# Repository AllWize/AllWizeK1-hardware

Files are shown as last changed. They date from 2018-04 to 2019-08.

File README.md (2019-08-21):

# AllWize K1

The Allwize K1 shield is an Arduino-compatible shield based on the RadioCrafts RC1701HP module. 

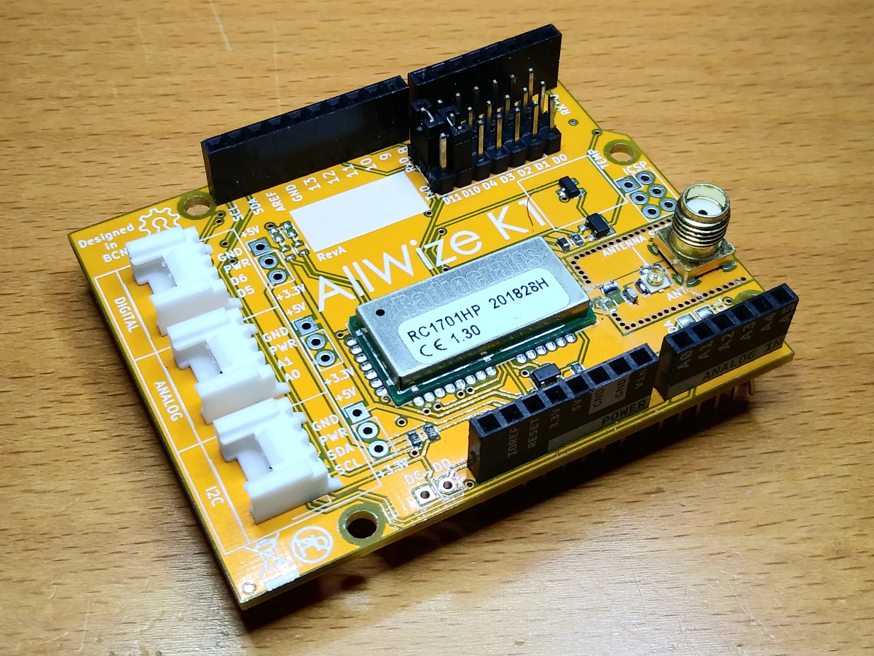
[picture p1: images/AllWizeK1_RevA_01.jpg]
AllWize K1 RevA


Resources:

* [AllWize K1 Wiki Page](http://wiki.allwize.io/index.php?title=Allwize_K1)
* [AllWize Library](https://github.com/AllWize/allwize) that supports the RC1701HP radio module.

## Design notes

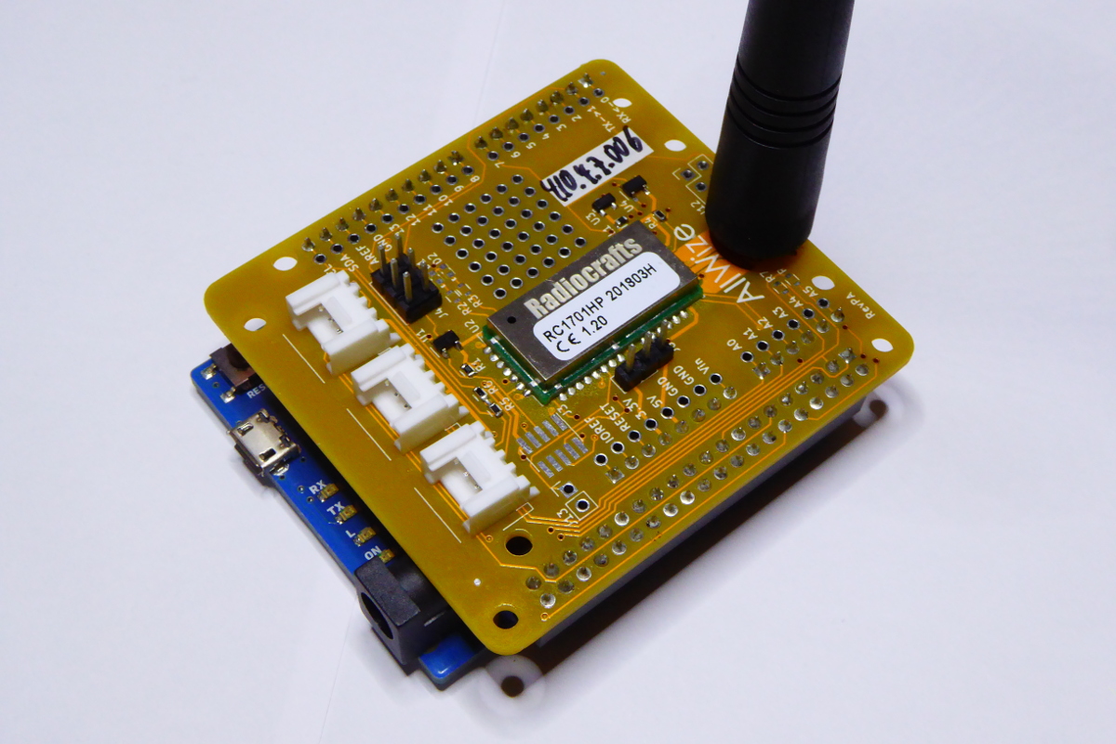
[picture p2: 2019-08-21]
images/AllWizeK1_RevPA_01.jpg

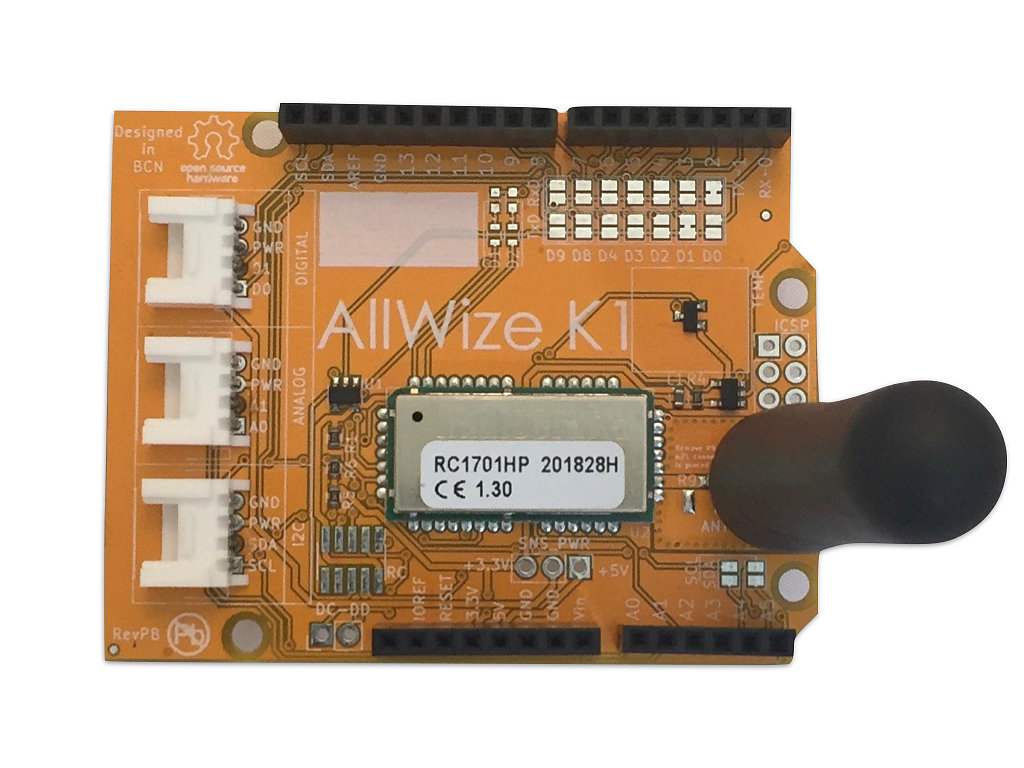
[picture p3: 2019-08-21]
images/AllWizeK1_RevPB_01.jpg

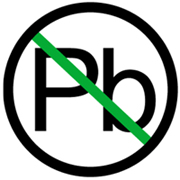
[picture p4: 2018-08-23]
RevA/Pb-free.jpg

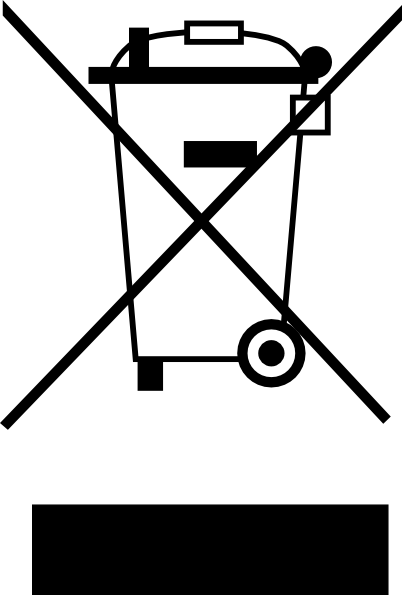
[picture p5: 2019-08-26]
RevA/WEEE.png

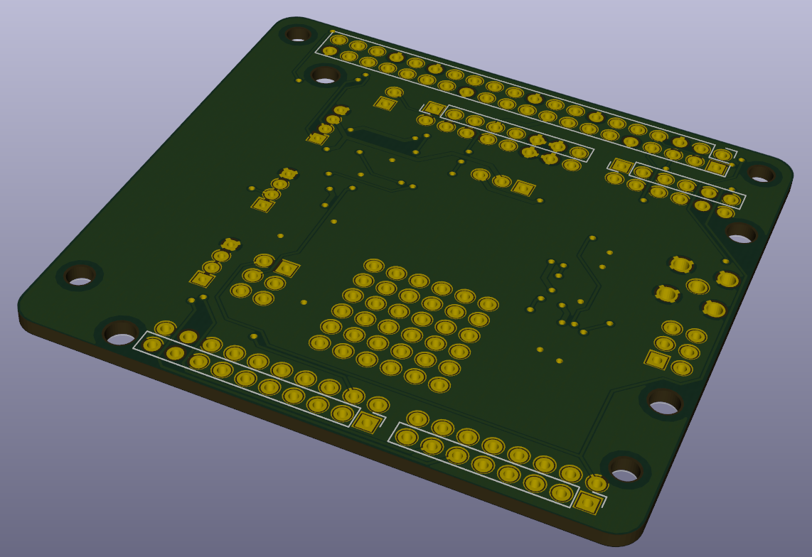
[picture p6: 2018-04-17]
RevPA/pcb/PCB-view-2-BOTTOM.png

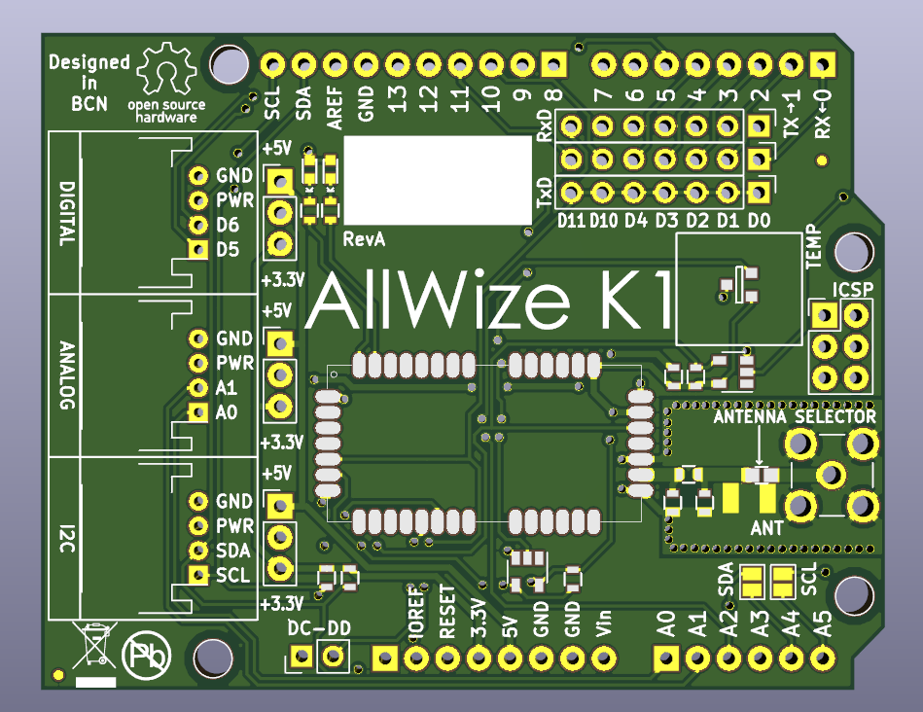
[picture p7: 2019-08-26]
RevA/gerbers/fanfkeofkpelmadl.png

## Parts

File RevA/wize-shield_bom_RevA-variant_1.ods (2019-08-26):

Part | References | Value | Quantity Per PCB | Function | PN | Populated
LED-DIODE | D1 D2 | LED-DIODE | 2 | Green LED | KPT-1608LVZGCK | No
LOGO | G2 | LABEL | 1 | Label Zone | NA | No
LOGO | G1 | LOGO | 1 | Logo Mark | NA | No
LOGO | G3 | PROTOTYPE-AREA | 1 | 6x6 Prototype Area | NA | No
Conn_01x02 | J13 | Conn_01x02 | 1 | 1x2 Connector | NA | No
Conn_01x03 | J6 J19 J20 | Conn_01x03 | 3 | 1x3 Connector | PEC03SAAN | Yes | https://www.digikey.es/products/es?keywords=PEC03SAAN
Conn_01x04 | J7 J8 J9 | Conn_01x04 | 3 | 1x4 Connector | 110990037 | Yes | https://www.digikey.es/products/es?keywords=110990037
Conn_01x06 | J2 | Conn_01x06 | 1 | 1x6 Connector | PEC06SAAN | Yes | https://www.digikey.es/products/es?keywords=PEC06SAAN
Conn_01x06 | J24 | Conn_01x06 | 1 | 1x6 Connector | NA | No
Conn_01x07 | J14 J17 J18 | Conn_01x07 | 3 | 1x7 Connector | PEC07SAAN | Yes | https://www.digikey.es/products/es?keywords=PEC07SAAN
Conn_01x08 | J1 J11 | Conn_01x08 | 2 | 1x8 Connector | PEC08SAAN | Yes | https://www.digikey.es/products/es?keywords=PEC08SAAN
Conn_01x08 | J23 J26 | Conn_01x08 | 2 | 1x8 Connector | NA | No
Conn_01x10 | J10 | Conn_01x10 | 1 | 1x10 Connector | PEC10SAAN | Yes | https://www.digikey.es/products/es?keywords=PEC10SAAN
Conn_01x10 | J25 | Conn_01x10 | 1 | 1x10 Connector | NA | No
Conn_02x03_Odd_Even | J12 | Conn_02x03_Odd_Even | 1 | 2x3 Connector | NA | No
Conn_02x03_Odd_Even | J4 | Conn_02x03_Odd_Even | 1 | 2x3 Connector | PEC03DAAN | Yes | https://www.digikey.es/products/es?keywords=PEC03DAAN
Conn_02x05_Odd_Even | J3 | Conn_02x05_Odd_Even | 1 | 2x5 Connector | NA | No
Conn_02x20_Odd_Even | J14 | Conn_02x20_Odd_Even | 1 | 2x20 Connector | PPTC202LFBN-RC | Yes | https://www.digikey.es/products/es?keywords=PPTC202LFBN-RC
Conn_Coaxial | J5 | Conn_Coaxial | 1 | SMA Antenna Connector | PCB.SMAFST.J.A.HT | Yes | https://www.digikey.es/product-detail/es/taoglas-limited/PCB.SMAFST.J.A.HT/931-1173-ND/3522339
NPTH-HOLE | J15 J16 J17 J18 J19 J20 J21 J22 | NPTH-HOLE | 8 | NPTH Hole | NA | No
Ferrite_Bead | L1 | Ferrite_Bead | 1 | Ferrite Bead | BLM18SG331TN1 | Yes | https://www.digikey.es/product-detail/es/murata-electronics-north-america/BLM18SG331TN1D/490-3997-1-ND/1016257
--------------------- | R7 R8 R10 | PI Filter | --------------------- | --------------------- | TBD
R | R2 R3 | 1k | 2 | Series Resistor | RC0603FR-071KL | No
R | R4 R5 R6 | 5k6 | 3 | Pull-up resistor | ERJ-3EKF5601V | Yes | https://www.digikey.es/product-detail/es/panasonic-electronic-components/ERJ-3EKF5601V/P5.60KHCT-ND/1746792
R | R1 | 8k2 | 1 | Pull-up resistor | CRCW06038K20FKEA | Yes | https://www.digikey.es/product-detail/es/vishay-dale/CRCW06038K20FKEA/541-8.20KHCT-ND/1179913
MCP9701 | U3 | MCP9701 | 1 | Temperature Sensors | MCP9701T-E/TT | Yes | https://www.digikey.es/product-detail/es/microchip-technology/MCP9701T-E-TT/MCP9701T-E-TTCT-ND/1987446
RC1701xx-MBUS | U2 | RC1701xx-MBUS | 1 | M-Bus High power RF Transceiver Module | RC1701HP-MBUS4 | Yes | https://www.digikey.es/product-detail/es/radiocrafts-as/RC1701HP-MBUS4/1783-1048-1-ND/7100650
SN74LV1T34 | U1 U4 | SN74LV1T34 | 2 | Logic Level Shifter | SN74LV1T34DBVR | Yes | https://www.digikey.es/product-detail/es/texas-instruments/SN74LV1T34DBVR/296-37176-1-ND/4555593
uFL | J4 | U.FL-R-SMT(10) | 1 | u.FL Antenna Connector | U.FL-R-SMT(10) | No | https://www.digikey.es/products/es?keywords=%20H9161CT-ND
R | R9 | 0R | 1 | Series Resistor | CRCW06030000Z0EAC | Yes
Jumper |  |  | 1 | Jumper | 969102-0000-DA | Yes | https://www.digikey.es/products/es?keywords=969102-0000-DA

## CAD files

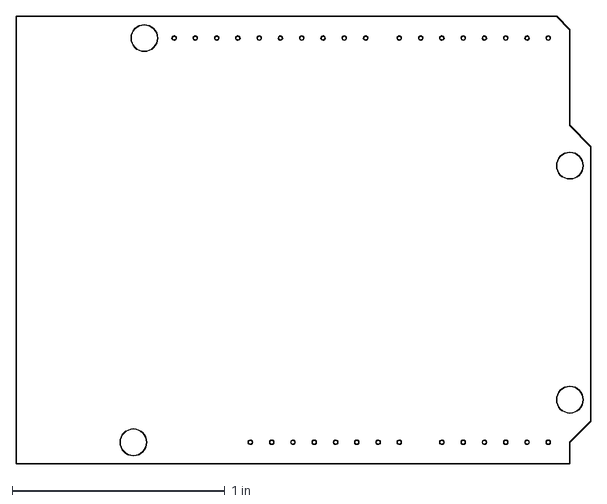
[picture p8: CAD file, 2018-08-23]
RevA/Arduino UNO R3 shield - full.dxf
2.70 x 2.10 in

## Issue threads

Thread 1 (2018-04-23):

[AllWize] Via annular ring too short (General)

amejias, 2018-04-23:
Some pads needs more annular ring space. This can provoke bad fixation on PCB.

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

xoseperez, 2018-09-19:
Fixed with RevPB

Closed 2018-09-19.

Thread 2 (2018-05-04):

[Allwize] Missing assembly plan

arcediano90, 2018-05-04:
Missing designators J1, J2, J10, J11, J14

xoseperez, 2018-09-19:
Is there an assembly plan already?

AllWize, 2018-11-16:
Already on the repository ... documents .Fab

Closed 2018-11-16.

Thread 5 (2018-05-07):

[Allwize] Missing info in the silkscreen

AllWize, 2018-05-07:
I'm missing proper information in the silkscreen for these designators

- J3 (RC programming header) - RC
- J4 (serial selector) - UART
- J6 (sensor reference) - SNS_PWR
- J7 (I2C grove connector) - I2C
- J8 (Analog grove connector: A0, A1) - ANA
- J9 (Digital grove connector: D5, D6) - DIO
- J12 (ICSP) - ICSP
- J13 (module flashing, not sure this is needed since it's still a testing feature)

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

xoseperez, 2018-09-19:
Fixed with RevPB

Closed 2018-09-19.

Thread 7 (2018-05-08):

[Allwize] Indicate jumper configuration

arcediano90, 2018-05-08:
Indicate in silkscreen the jumper configuration

xoseperez, 2018-09-19:
Fixed with Rev.PB for the only jumper left, the sensor power jumper.

Closed 2018-09-19.

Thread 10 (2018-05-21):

Mark the temperature sensor as "Temperature sensor" not "Ux"

mfabregas, 2018-05-21:
Will give a better understanding and user experience if the user knows which IC is the temperature sensor, in order to play with it. Since he/she likely will touch it, will be good to have it in an accessible location, far from other ICs, jumpers and components

xoseperez, 2018-09-19:
Done with Rev.PB

Closed 2018-09-19.

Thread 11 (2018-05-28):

Grove connector pins are swapped

xoseperez, 2018-05-28:
The pins in the grove connectors are swapped, we should swap pin 1 with 4 and 2 with 3

xoseperez, 2018-09-19:
Fixed with Rev.PB

Closed 2018-09-19.

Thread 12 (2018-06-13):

Use stackable headers & remove proto zone

AllWize, 2018-06-13:
Even if the K1 is forced to be a top-shield, it is interesting to mount stackable headers (with female holes on top) so there is no need to solder the extra rows of headers to have easy access to other GPIOs.

xoseperez, 2018-09-19:
Done with Rev.PB

xoseperez, 2018-09-19:
BTW, see https://store.arduino.cc/headers-strip-14-ways-arduino-mkr1000-printed

Closed 2018-09-19.

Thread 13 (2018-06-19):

Replace the arrows in the silkscreen

AllWize, 2018-06-19:
At the moment the arrow in the RX/TX ports is done using two characters (-> or <-). In order to save some room it will be interesting to use a single character symbol.

xoseperez, 2018-09-19:
Fixed with Rev.PB

Closed 2018-09-19.

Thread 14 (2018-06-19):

Remove Raspberry Pi Connector

AllWize, 2018-06-19:
We will think about creating a G1 version in the future for Raspberry Pi, but at the moment we don't see any benefit in having the Raspberry Pi header in the K1.

xoseperez, 2018-09-19:
Done with Rev.PB

Closed 2018-09-19.

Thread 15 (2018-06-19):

Add uFL footprint

AllWize, 2018-06-19:
The main benefit is that we will not be limited to be a top shield. Right now the issue is the lack of (good) 90 degrees antenna.

It's OK if it's to factory-ready that would require a solder-jumper change.
Or even better, place the uFL footprint in the path, not mounted, and a resistor bridge that should be removed before placing the uFL, the same pad of the resistor would double and uFL live.

xoseperez, 2018-09-19:
Done with Rev.PB

Closed 2018-09-19.

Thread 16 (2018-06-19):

Use hardware serial by default

AllWize, 2018-06-19:
We think it will ease the use of the board to remove the jumper selector and set it to hardware serial by default with solder pads to allow the user to cut and solder a different option. Very much like this board:

https://github.com/ttn-liv/LoRaWANshield

Options: 0 (default for RX),1 (default for TX), 2, 3, 4, 8 and 9.

xoseperez, 2018-09-19:
Done with Rev.PB

Closed 2018-09-19.

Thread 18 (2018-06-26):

General labelling

xoseperez, 2018-06-26:
Several changes:

* Board must be named "Allwize K1"
* Make the while label zone bigger
* Increase font size, make it the same size as an Arduino
* Add as much GND as possible on both sides
* OSH logo (on top) (https://www.oshwa.org/open-source-hardware-logo/)
* "Made in BCN"
* Compliance logos (CE, ~~ROHS~~)

xoseperez, 2018-09-19:
Done with Rev.PB

Closed 2018-09-19.

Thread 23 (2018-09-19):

Add BOM to the repository

xoseperez, 2018-09-19:
A BOM file (no special format required) must be added to the repo si be fully open source hardware.

xoseperez, 2018-09-19:
See https://store.arduino.cc/headers-strip-14-ways-arduino-mkr1000-printed for the headers reference.

AllWize, 2018-10-01:
@arcediano90 to add it

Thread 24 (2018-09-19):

Digital grove connector label is wrong

xoseperez, 2018-09-19:
It should state that the connected pins are D5 and D6, and not D0 and D1 as it says.

Closed 2018-12-19.

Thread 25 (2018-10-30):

Change Pin Header position

arcediano90, 2018-10-30:
For the future Revision, change the position pin header connector:

SNS_PWR connector (pin header) next to grove connectors

AllWize, 2018-11-16:
See issue #27

Closed 2018-11-16.

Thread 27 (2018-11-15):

Sensor's power pins next to connectors

AllWize, 2018-11-15:
It does not make sense to pot the power pins SNS_PWR so far from the connectors; why not putting it next to the Grove connector?
Moreover, maybe make sense to put one of them for each sensor

AllWize, 2018-11-16:
The label indicating the type of connector is moved to the board edge, where the connector is plugged (right now this is an empty space)

Closed 2018-12-18.

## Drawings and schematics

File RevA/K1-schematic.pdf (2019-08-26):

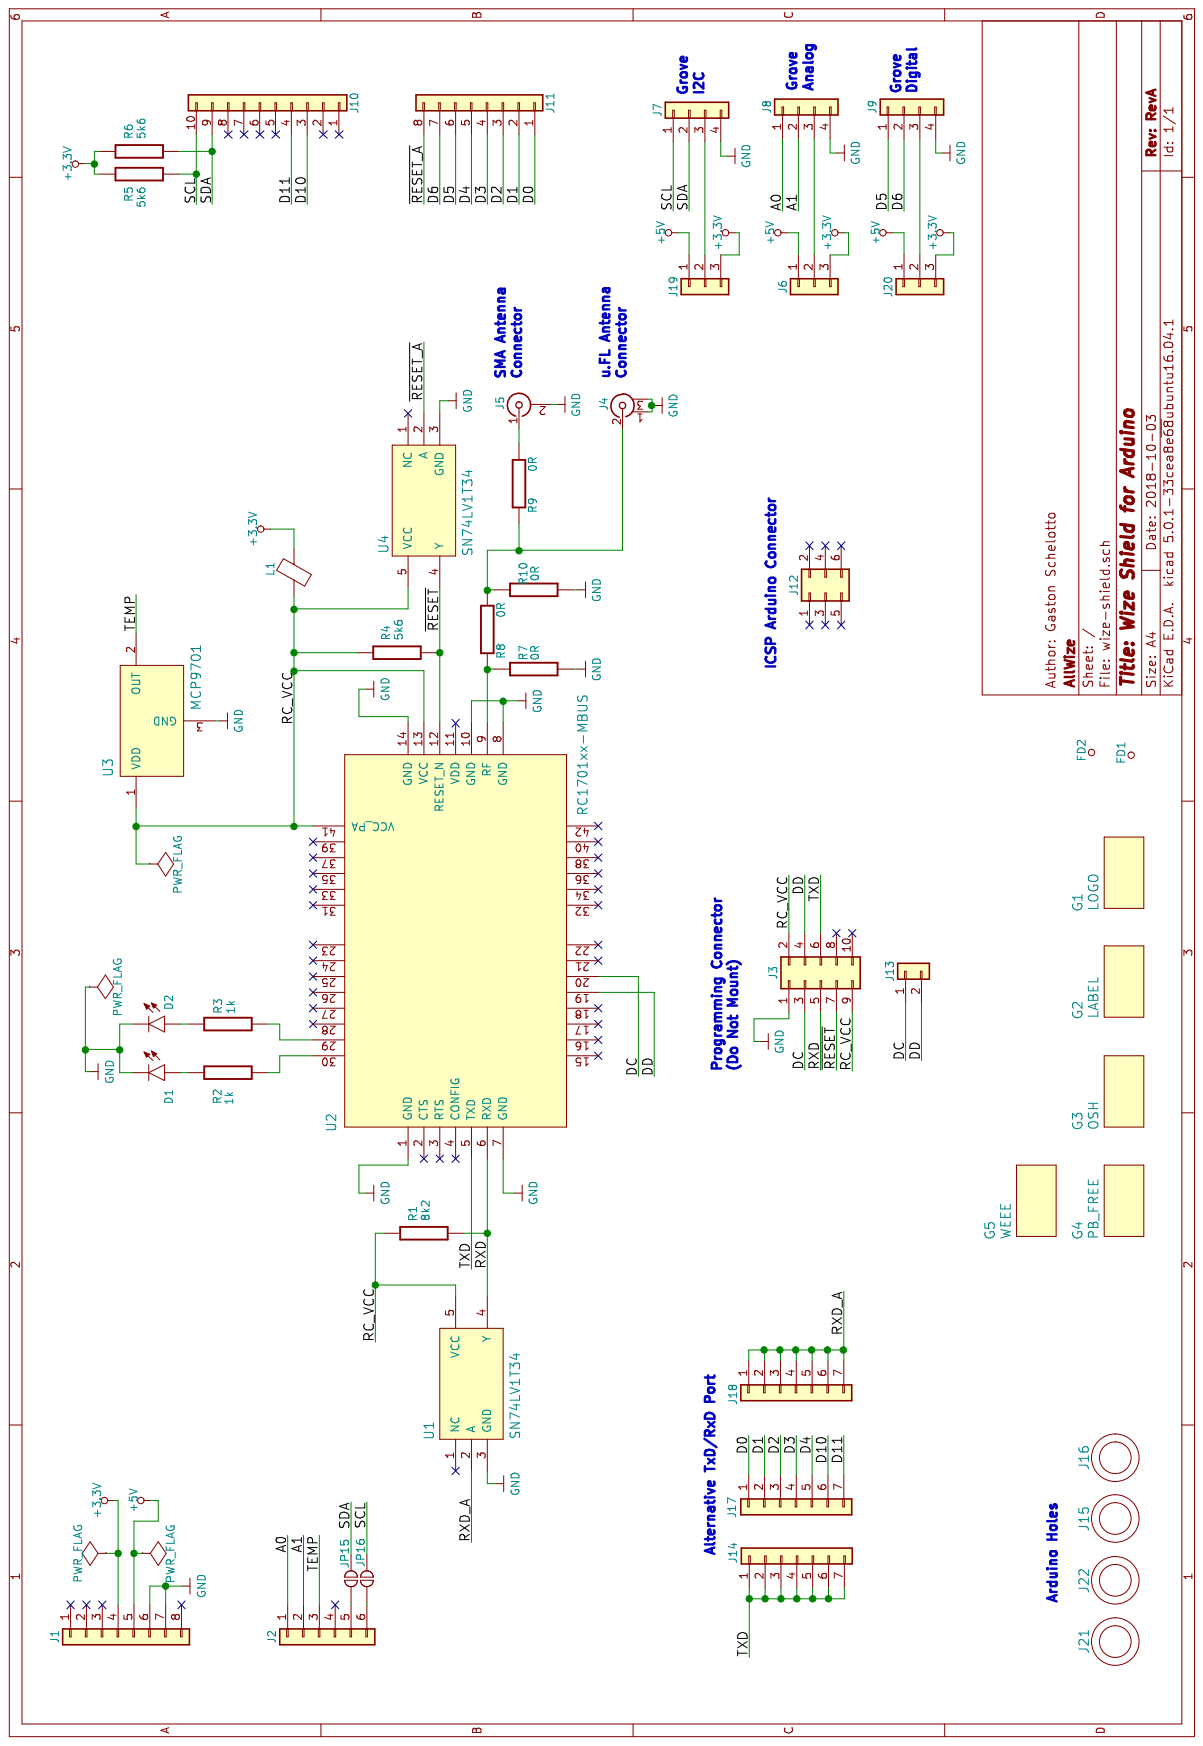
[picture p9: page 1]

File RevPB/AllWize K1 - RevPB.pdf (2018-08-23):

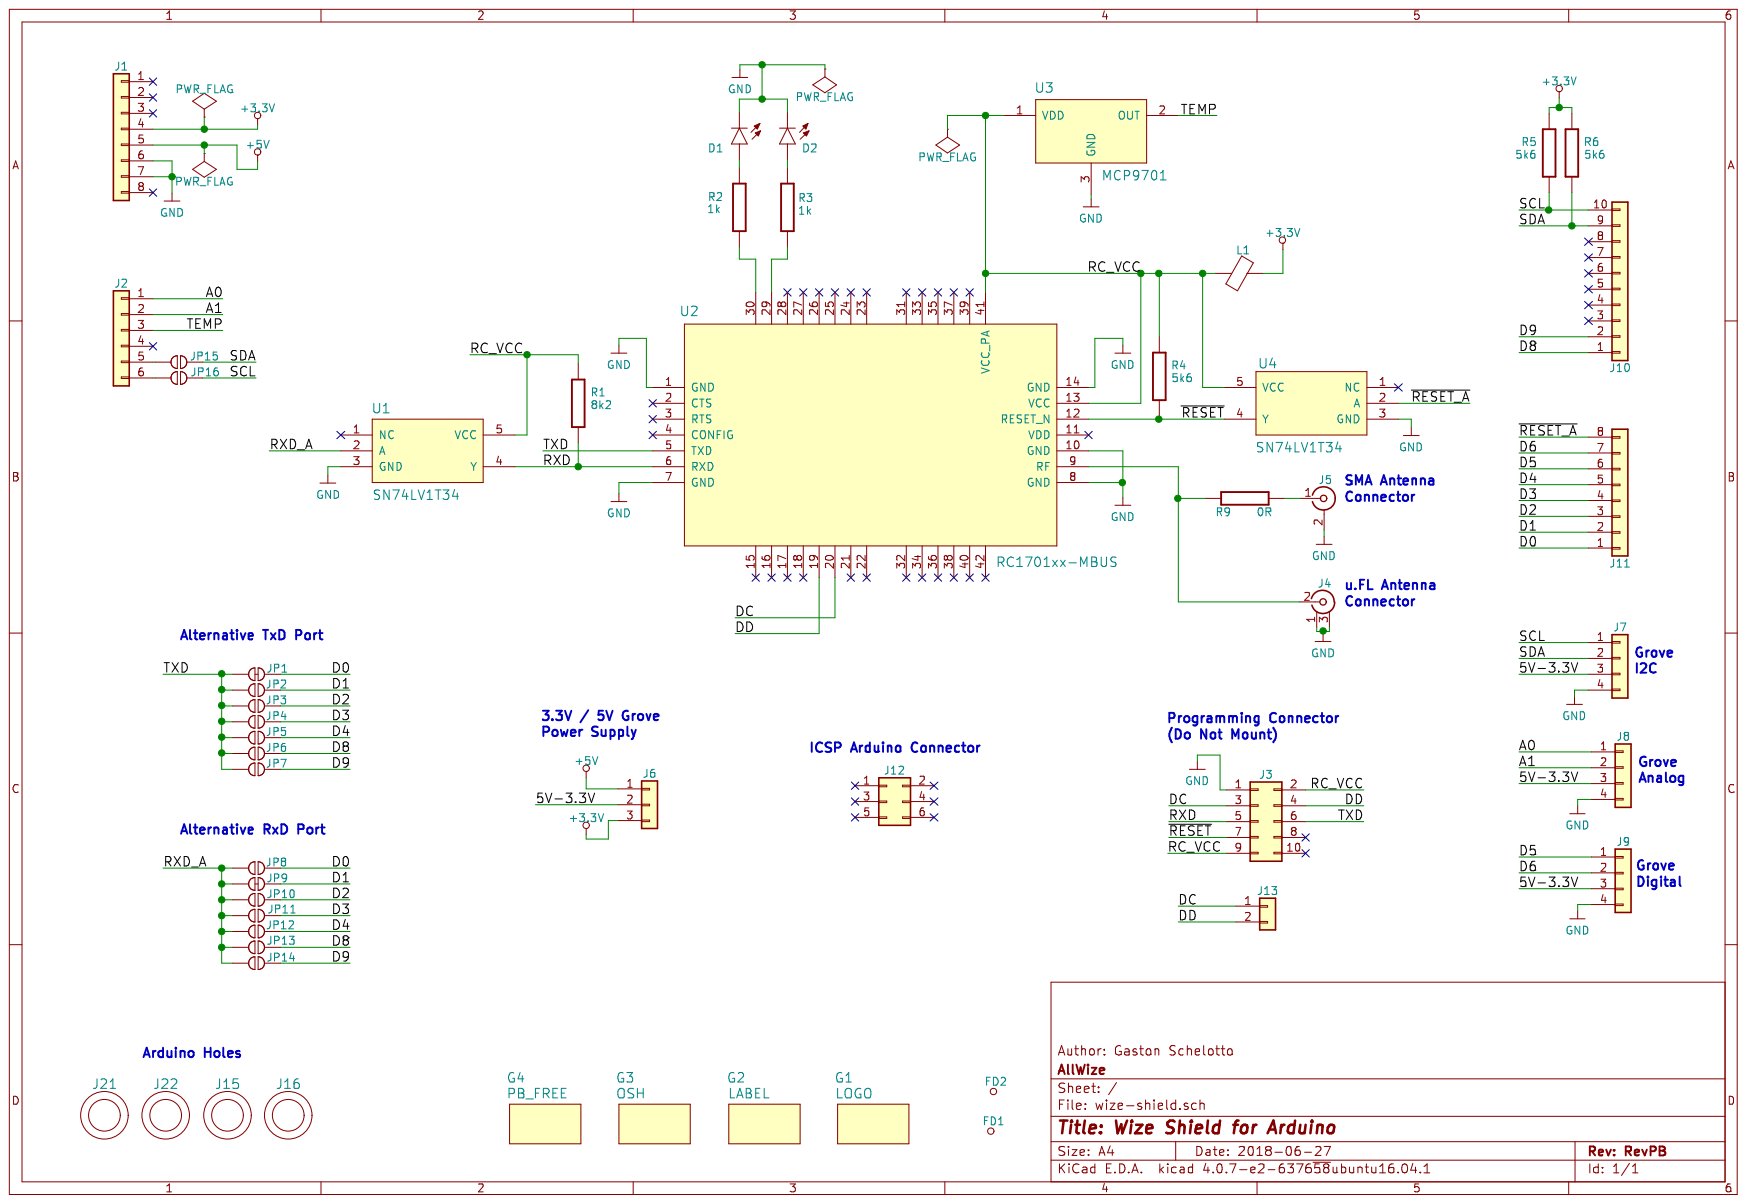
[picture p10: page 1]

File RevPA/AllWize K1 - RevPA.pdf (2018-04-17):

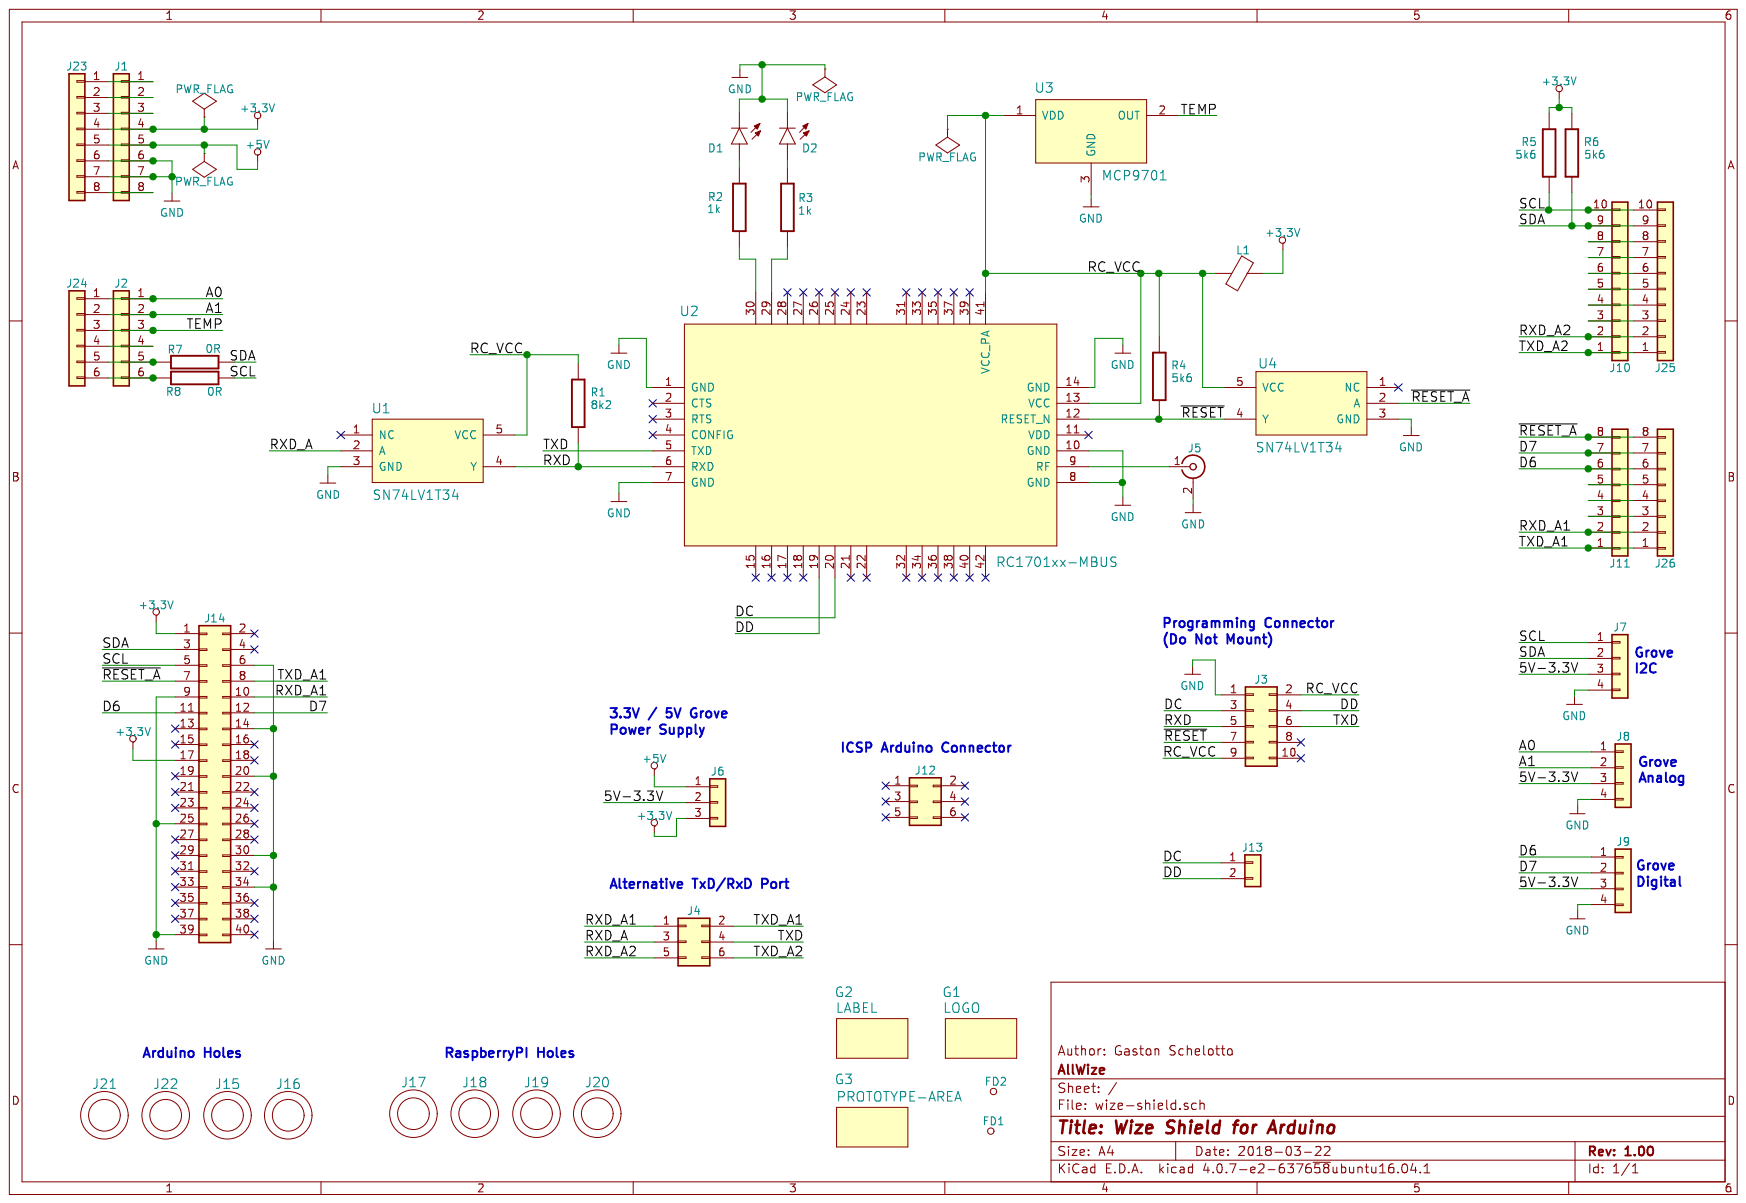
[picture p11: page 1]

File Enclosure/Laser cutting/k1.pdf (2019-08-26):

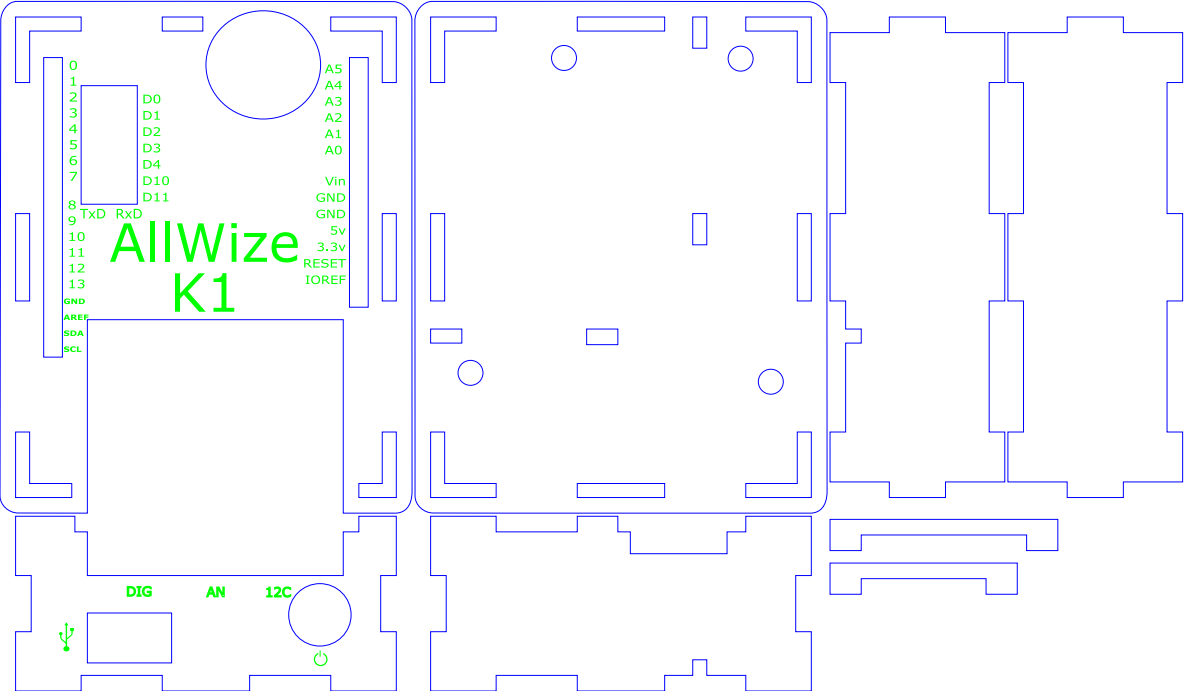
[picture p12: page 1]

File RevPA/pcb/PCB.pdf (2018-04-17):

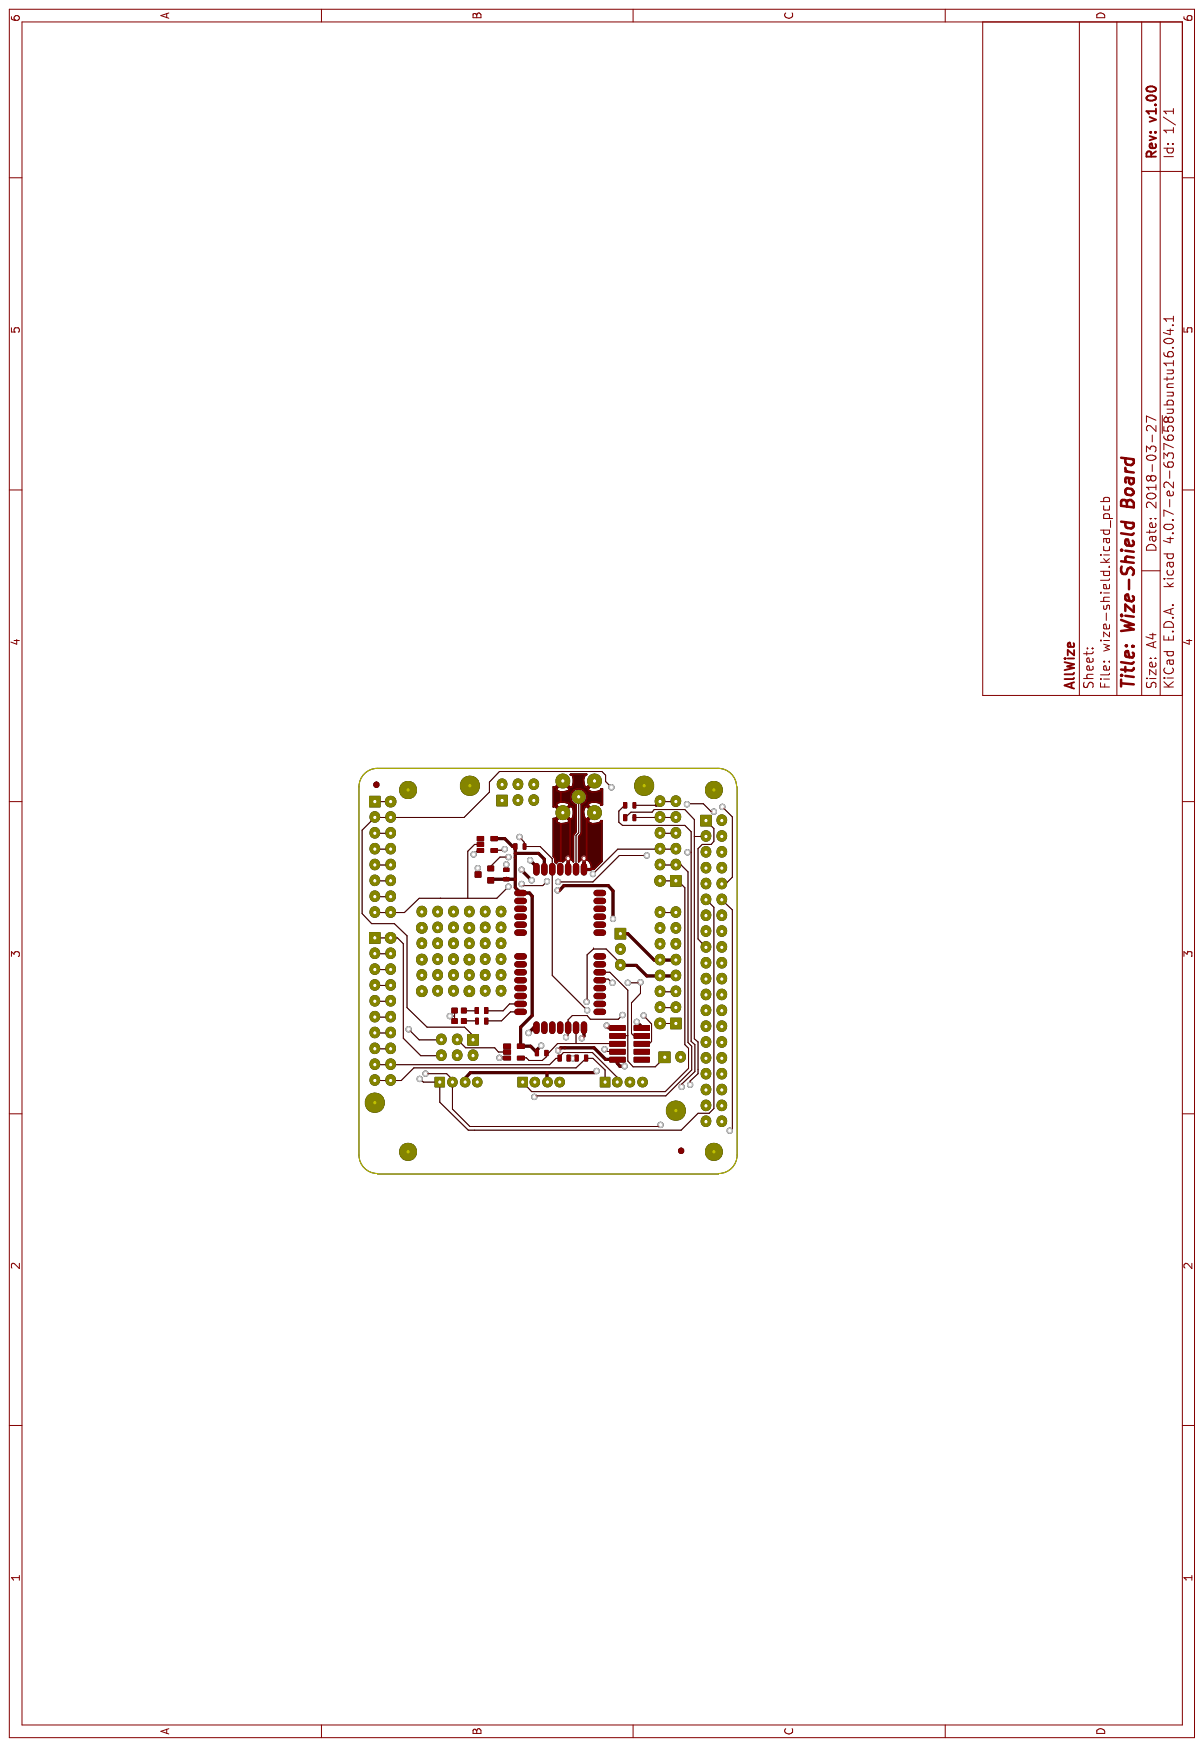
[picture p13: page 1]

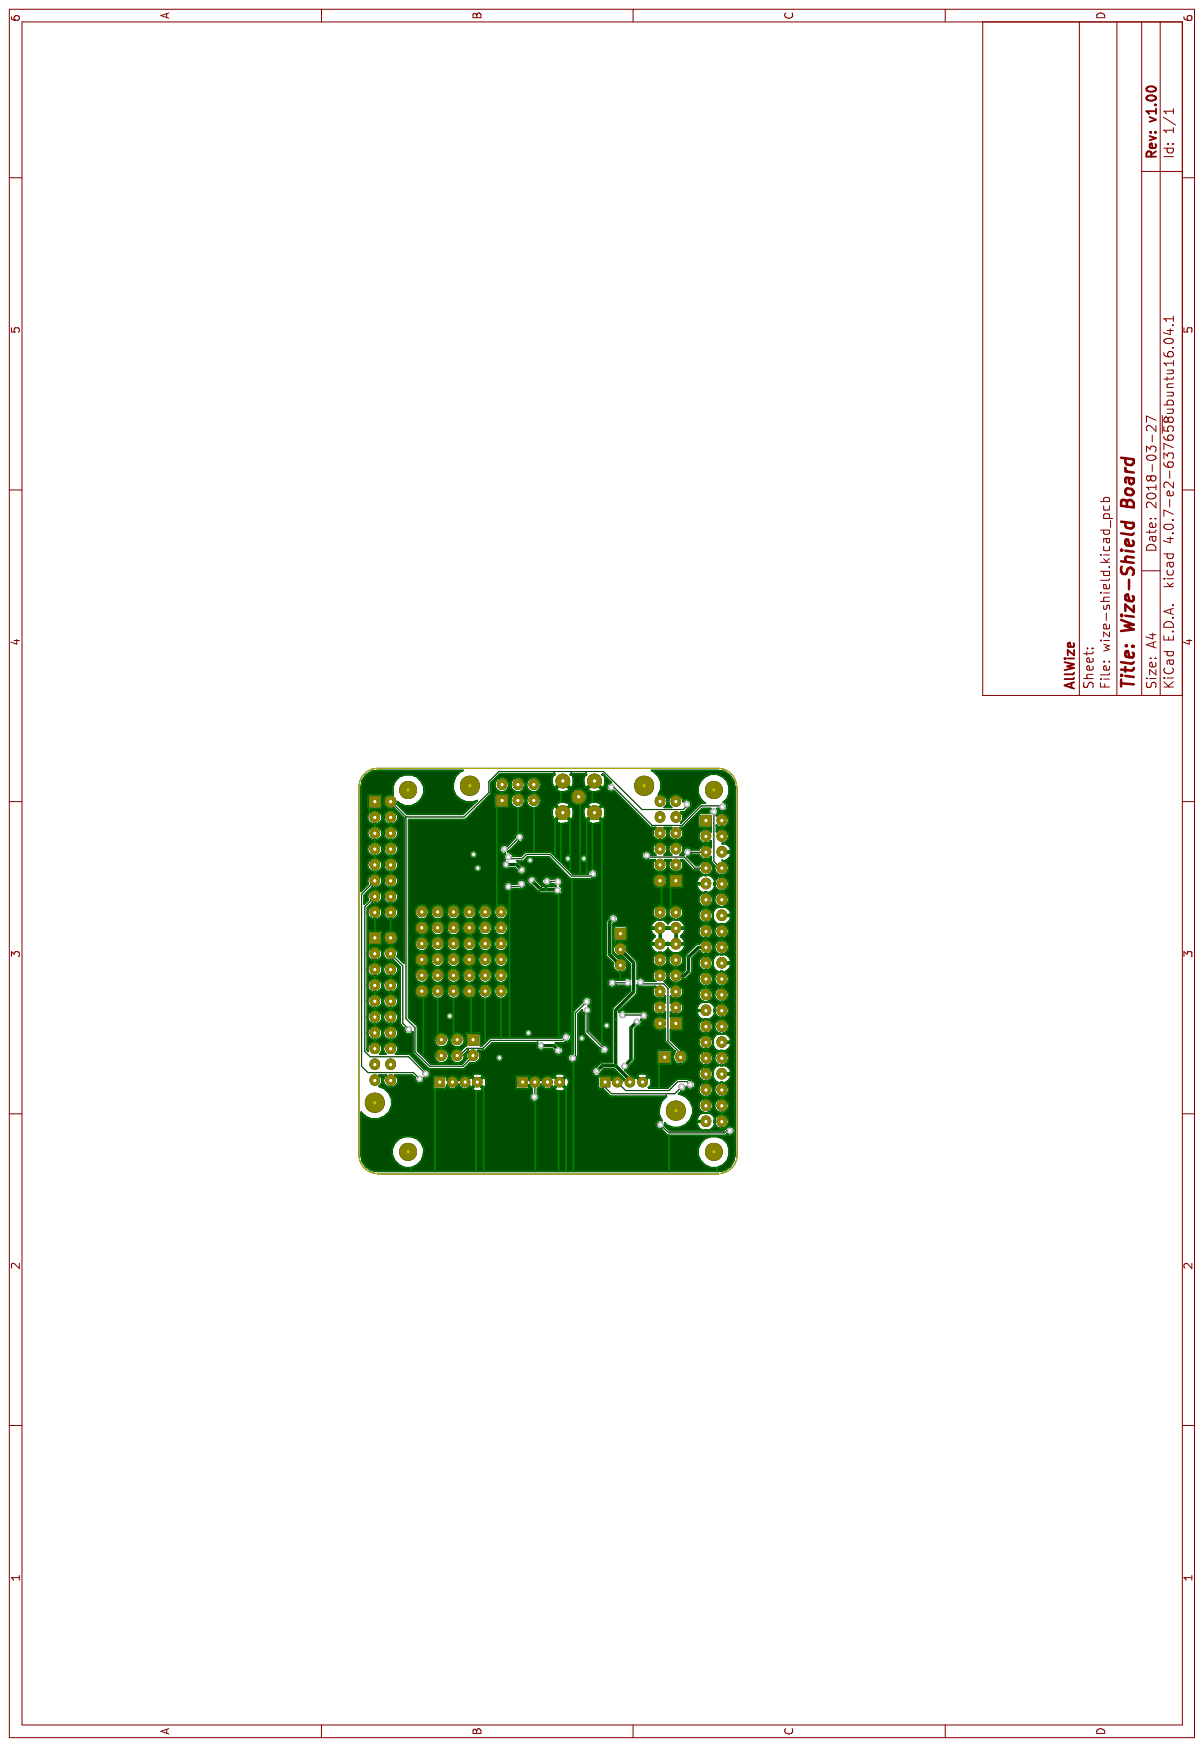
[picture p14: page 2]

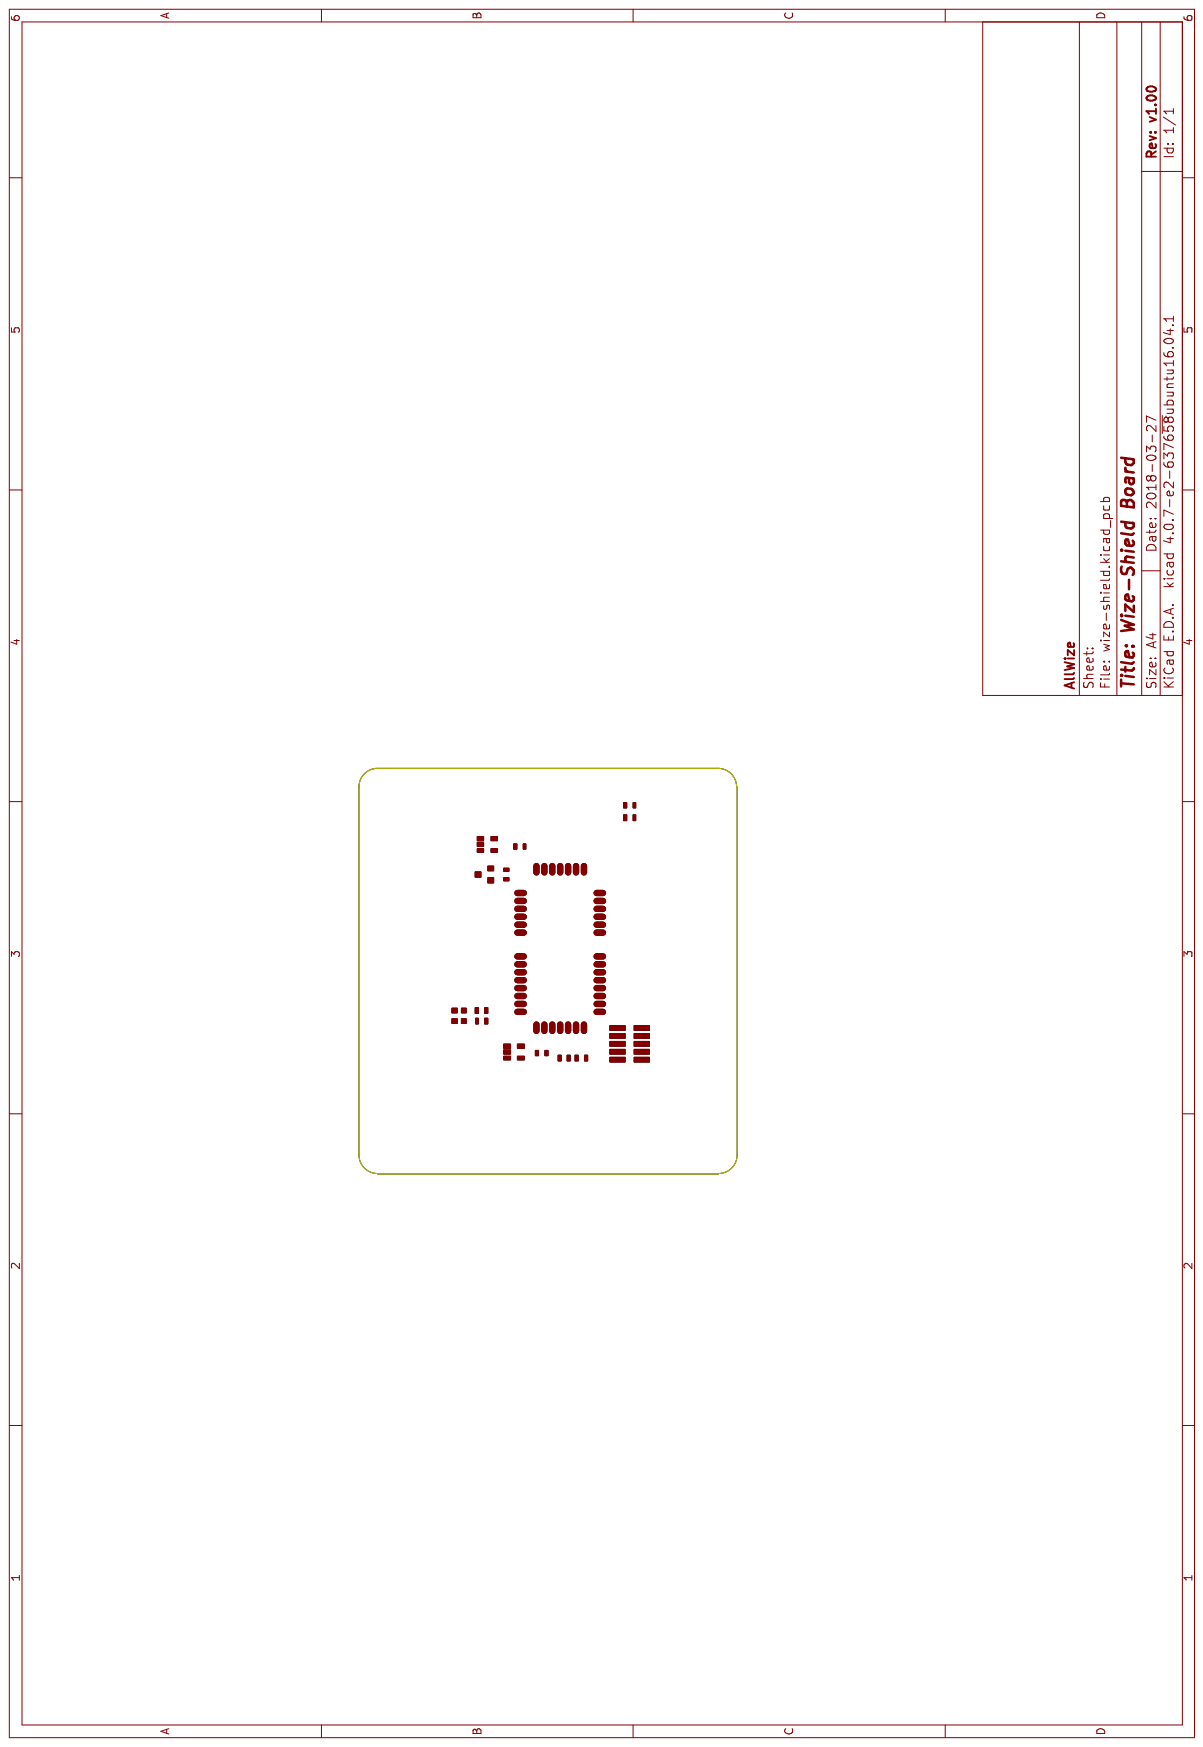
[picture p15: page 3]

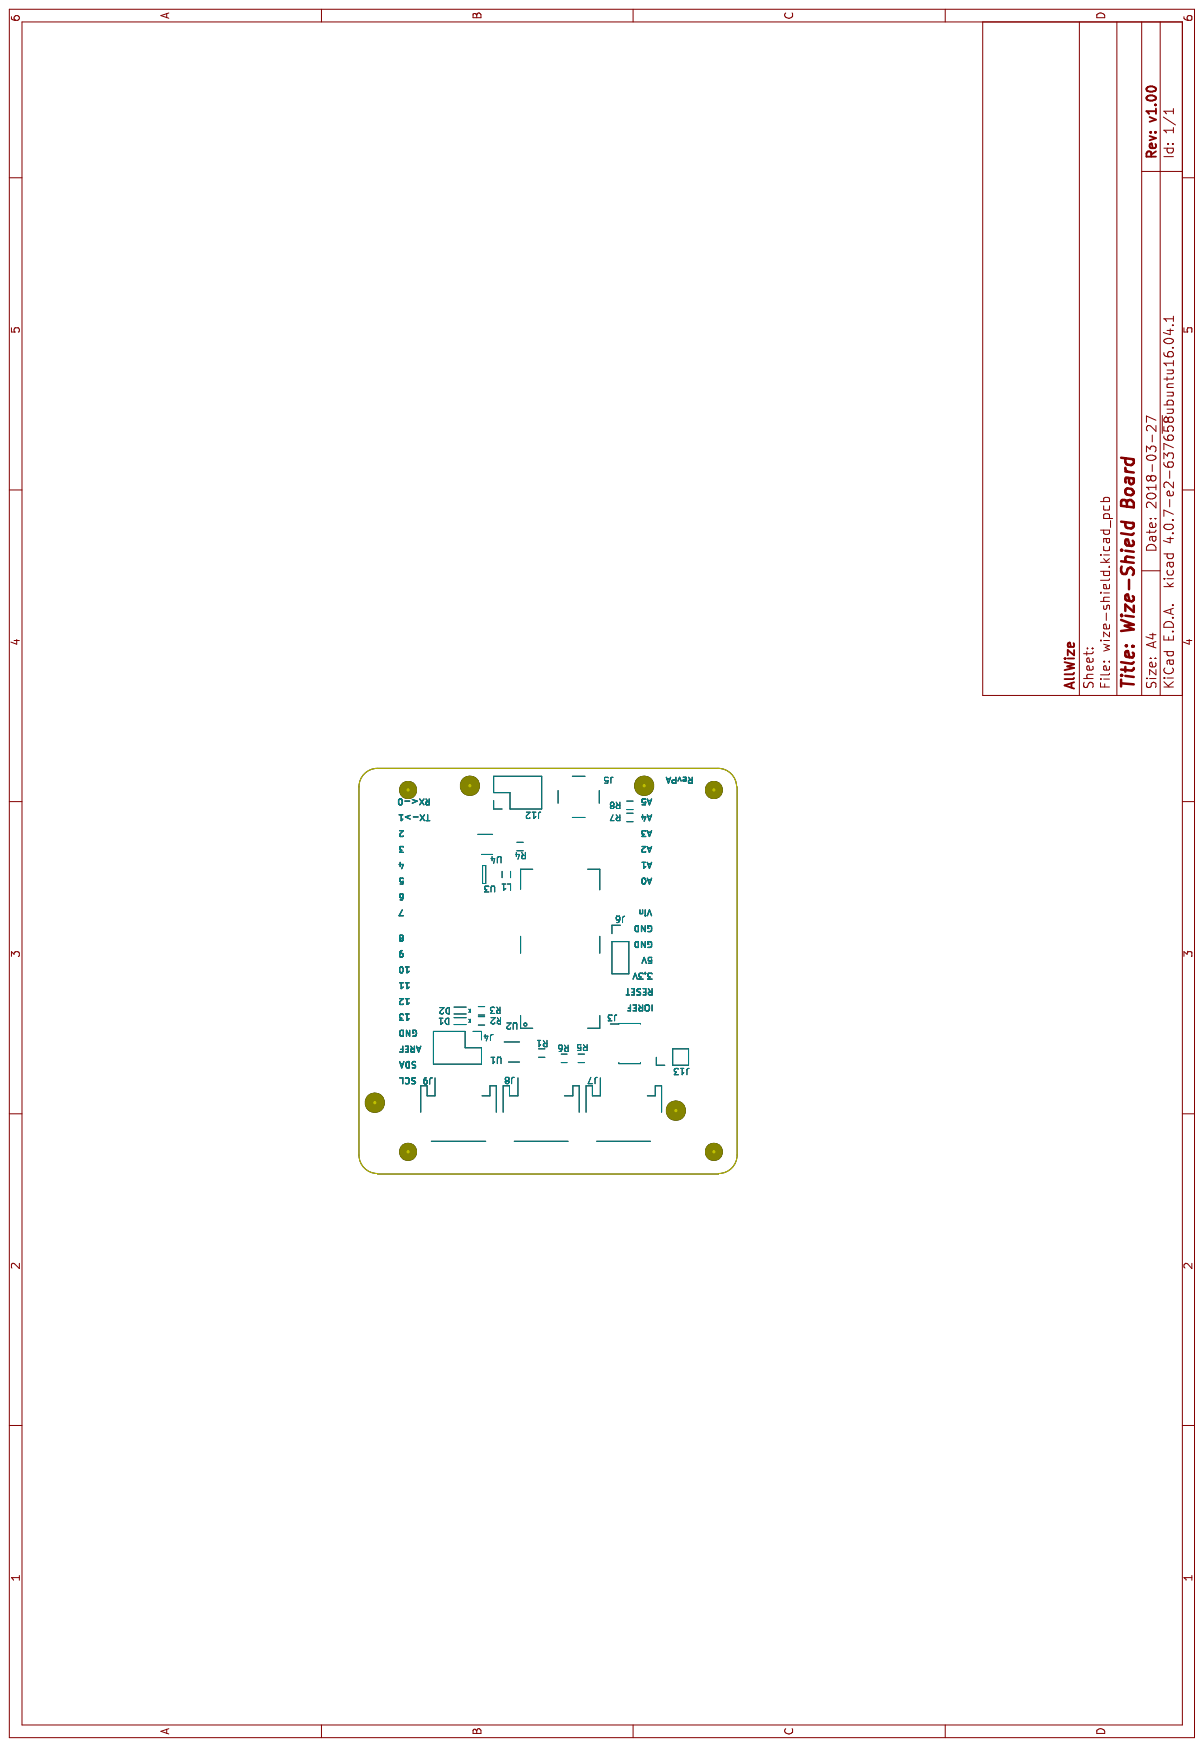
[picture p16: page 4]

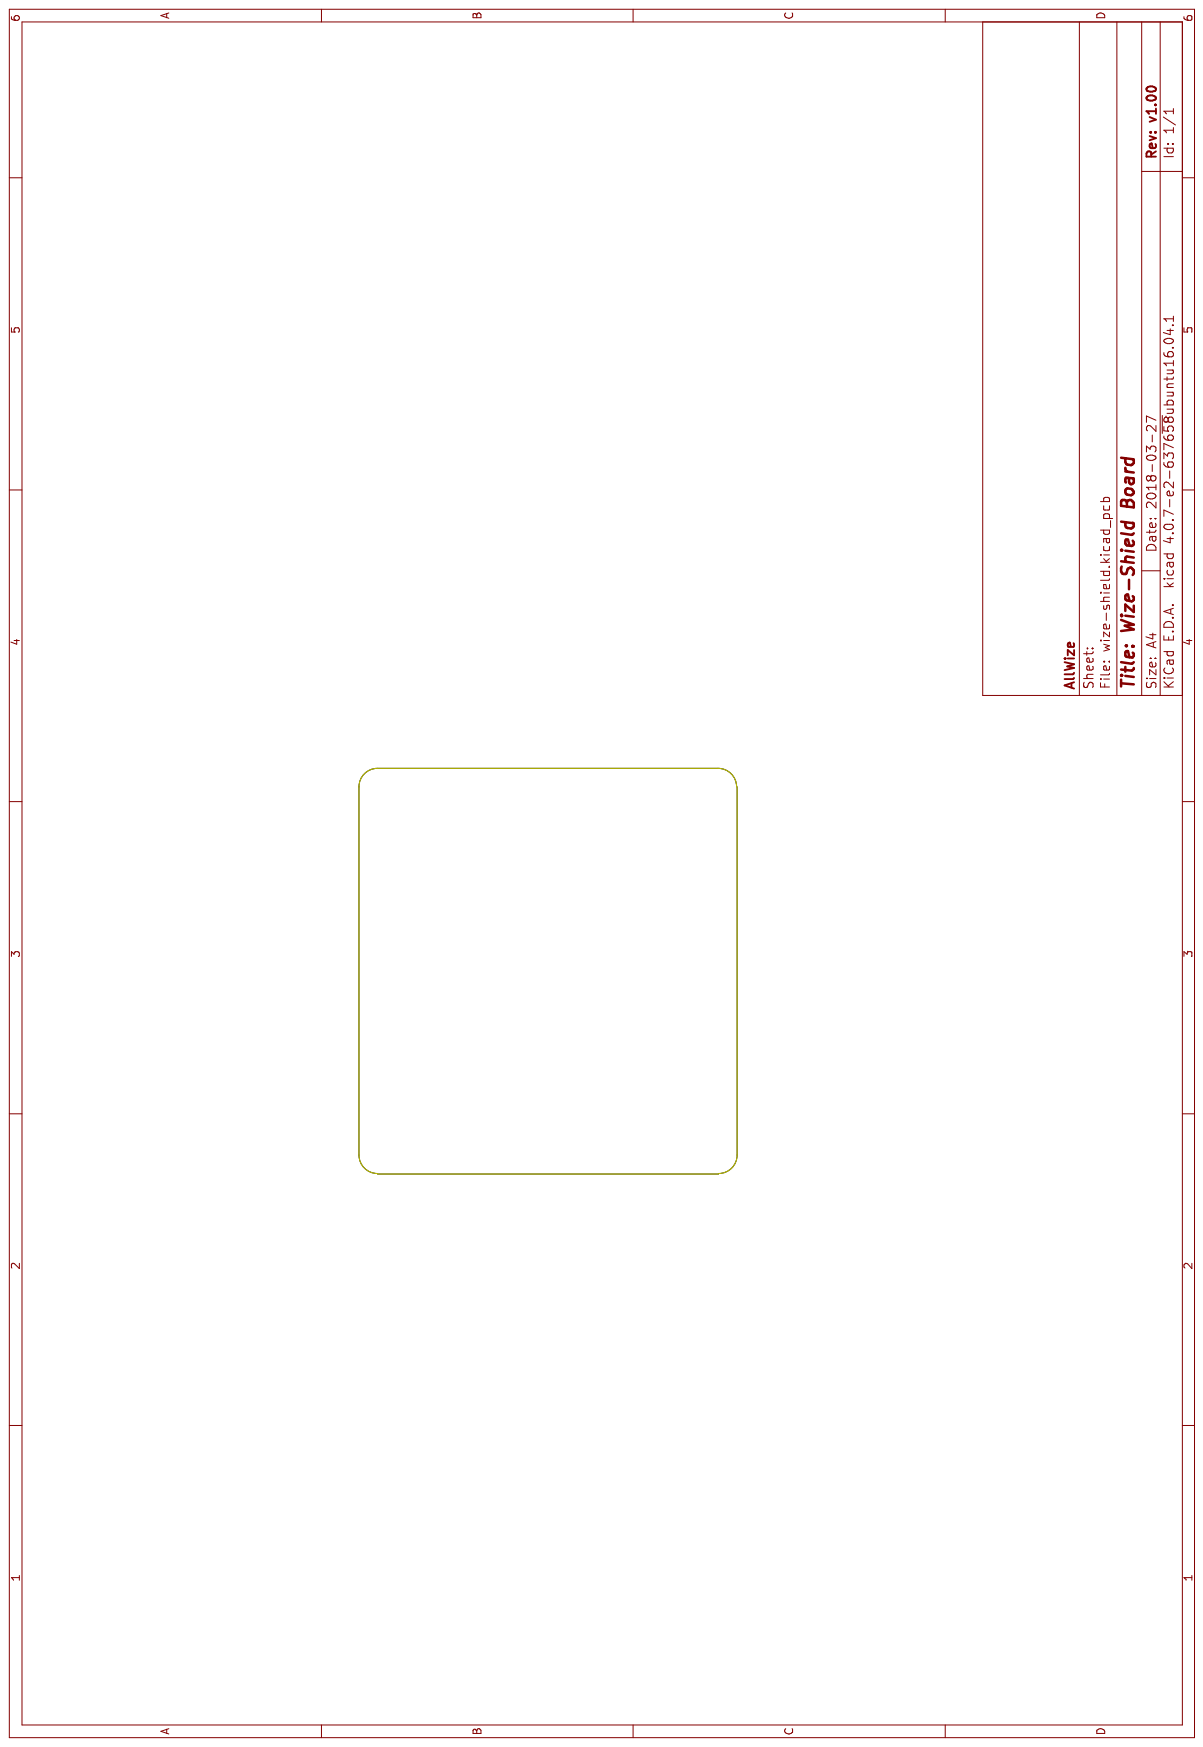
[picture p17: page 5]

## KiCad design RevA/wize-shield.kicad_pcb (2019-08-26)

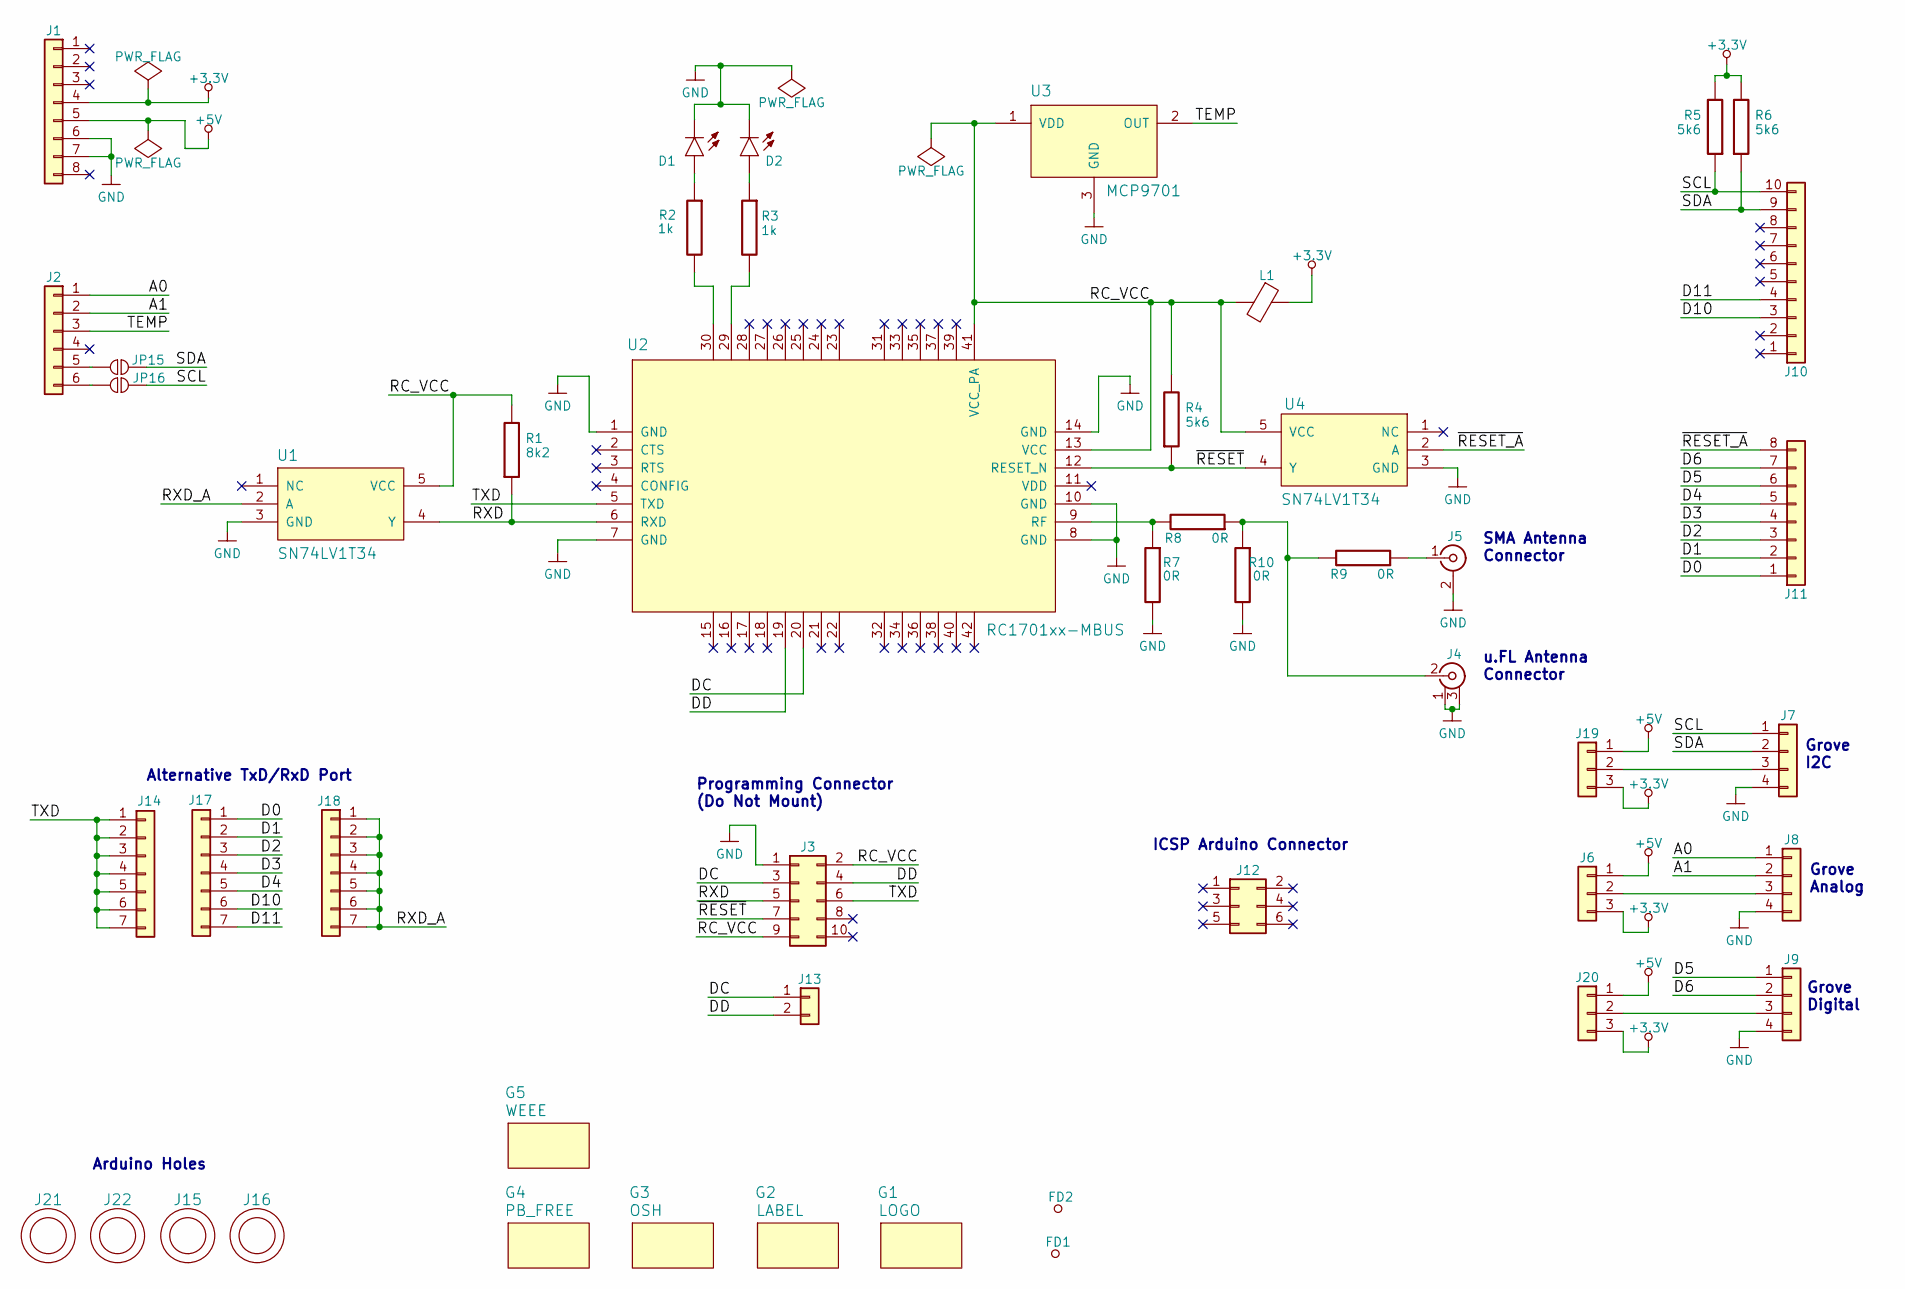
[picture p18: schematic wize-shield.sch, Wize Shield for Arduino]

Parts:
D1, D2: LED-DIODE; LED_0603
FD1, FD2: FIDUCIAL; FIDUCIAL-08
G1: LOGO; allwize-logo-2
G2: LABEL; LABEL_15x7mm
G3: OSH; osh
G4: PB_FREE; Pb-free
G5: WEEE
J1, J11: Conn_01x08; PinHeader_1x08_P2.54mm_Vertical
J2: Conn_01x06; PinHeader_1x06_P2.54mm_Vertical
J3: Conn_02x05_Odd_Even; PinHeader_2x05_P1.27mm_Vertical_SMD
J4: Conn_Coaxial_uFL; uFL-CONN
J5: Conn_Coaxial; SMA_Jack
J6, J19, J20: Conn_01x03; PinHeader_1x03_P2.54mm_Vertical
J7, J8, J9: Conn_01x04; GROVE-TH-1x04-P2.00mm_Horizontal
J10: Conn_01x10; PinHeader_1x10_P2.54mm_Vertical
J12: Conn_02x03_Odd_Even; PinHeader_2x03_P2.54mm_Vertical
J13: Conn_01x02; PinHeader_1x02_P2.54mm_Vertical
J14, J17, J18: Conn_01x07; PinHeader_1x07_P2.54mm_Vertical
J15, J16, J21, J22: NPTH-HOLE; HOLE_3.10MM
JP15, JP16: SolderJumper_2_Open; SolderJumper-2_P1.3mm_Open_Pad1.0x1.5mm
L1: Ferrite_Bead; R_0603
R1: 8k2; R_0603
R2, R3: 1k; R_0603
R4, R5, R6: 5k6; R_0603
R7, R8, R10: 0R; R_0603
R9: 0R; R_0603_ANTENNA
U1, U4: SN74LV1T34; SOT-23-5
U2: RC1701xx-MBUS
U3: MCP9701; SOT-23-3

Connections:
+3.3V: J1.4, J6.3, J19.3, J20.3, L1.1, R5.2, R6.2
+5V: J1.5, J6.1, J19.1, J20.1
/A0: J2.1, J8.1
/A1: J2.2, J8.2
/D0: J11.1, J17.1
/D1: J11.2, J17.2
/D2: J11.3, J17.3
/D3: J11.4, J17.4
/D4: J11.5, J17.5
/D5: J9.1, J11.6
/D6: J9.2, J11.7
/D10: J10.3, J17.6
/D11: J10.4, J17.7
/DC: J3.3, J13.1, U2.20
/DD: J3.4, J13.2, U2.19
/RC_VCC: J3.2, J3.9, L1.2, R1.2, R4.2, U1.5 (VCC), U2.13 (VCC), U2.41 (VCC_PA), U3.1 (VDD), U4.5 (VCC)
/RXD: J3.5, R1.1, U1.4 (Y), U2.6 (RXD)
/RXD_A: J18.1, J18.2, J18.3, J18.4, J18.5, J18.6, J18.7, U1.2 (A)
/SCL: J7.1, J10.10, JP16.2 (B), R5.1
/SDA: J7.2, J10.9, JP15.2 (B), R6.1
/TEMP: J2.3, U3.2 (OUT)
/TXD: J3.6, J14.1, J14.2, J14.3, J14.4, J14.5, J14.6, J14.7, U2.5 (TXD)
/~RESET_A~: J11.8, U4.2 (A)
/~RESET~: J3.7, R4.1, U2.12 (RESET_N), U4.4 (Y)
GND: D1.2 (C), D2.2 (C), J1.6, J1.7, J3.1, J4.1 (Ext), J4.3 (Ext), J5.2 (Ext), J7.4, J8.4, J9.4, R7.2, R10.2, U1.3 (GND), U2.1 (GND), U2.7 (GND), U2.8 (GND), U2.10 (GND), U2.14 (GND), U3.3 (GND), U4.3 (GND)
unnamed: D1.1 (A), R2.1
unnamed: D2.1 (A), R3.1
unnamed: J2.5, JP15.1 (A)
unnamed: J2.6, JP16.1 (A)
unnamed: J4.2 (In), R8.1, R9.2, R10.1
unnamed: J5.1 (In), R9.1
unnamed: J6.2, J8.3
unnamed: J7.3, J19.2
unnamed: J9.3, J20.2
unnamed: R2.2, U2.30
unnamed: R3.2, U2.29
unnamed: R7.1, R8.2, U2.9 (RF)

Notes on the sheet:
Programming Connector (Do Not Mount)
Alternative TxD/RxD Port
Grove I2C
Grove Analog
Grove Digital
ICSP Arduino Connector
Arduino Holes
SMA Antenna Connector
u.FL Antenna Connector

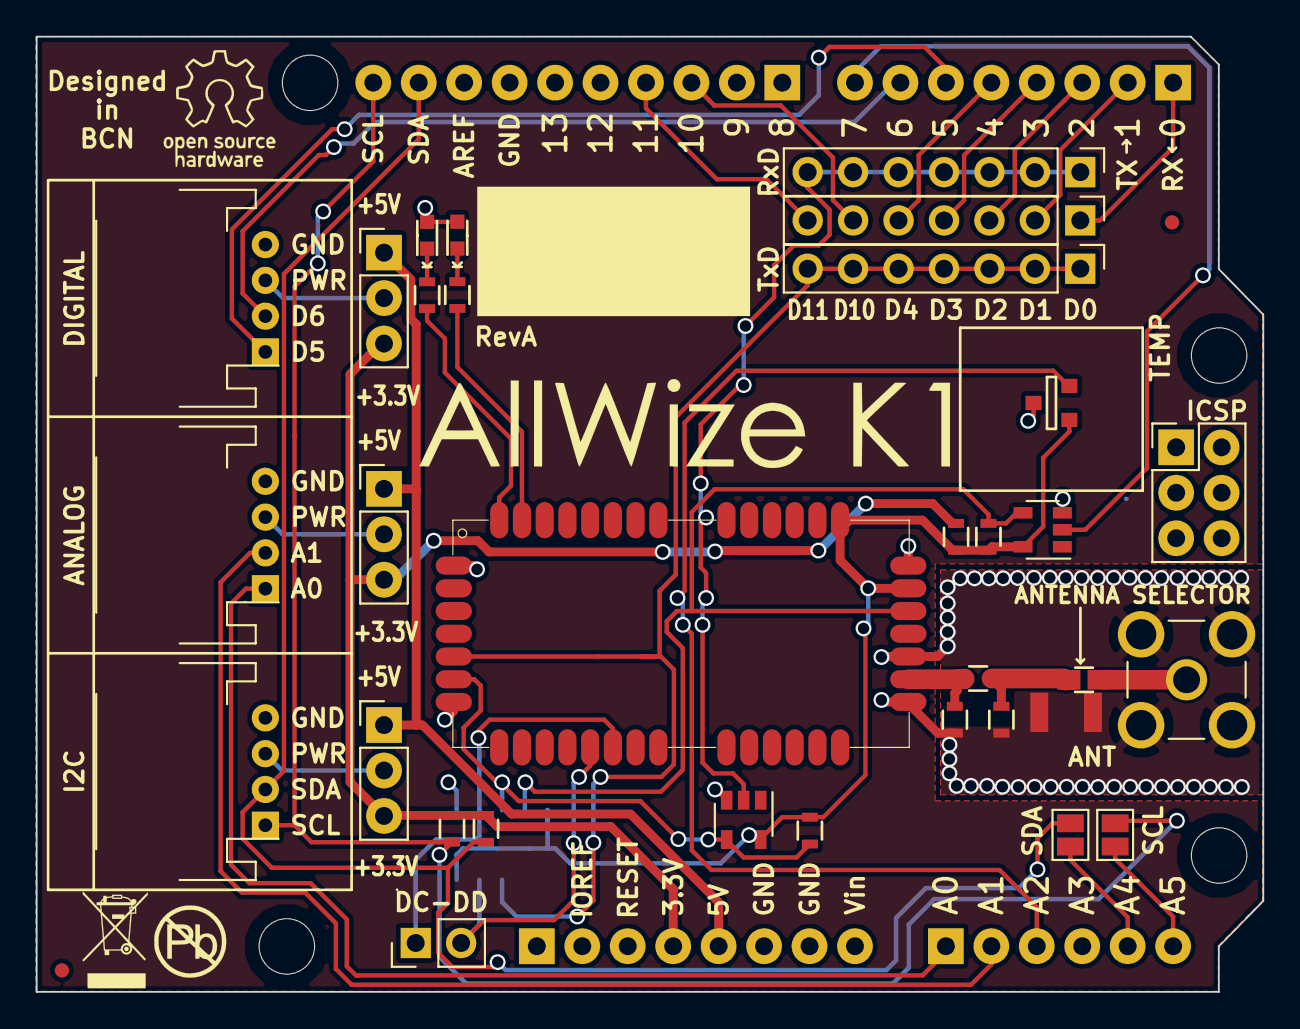
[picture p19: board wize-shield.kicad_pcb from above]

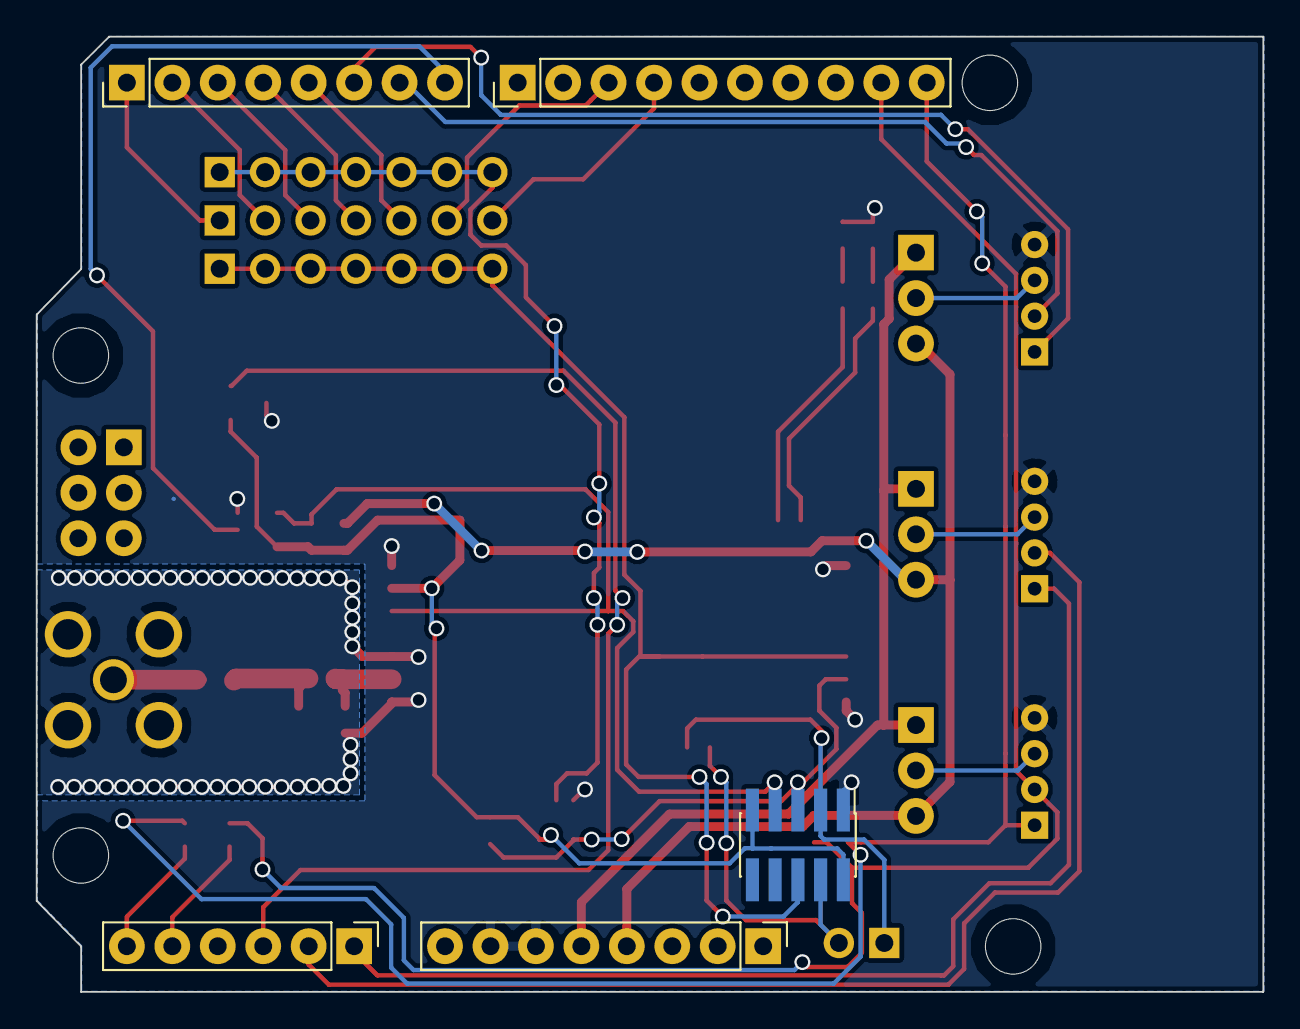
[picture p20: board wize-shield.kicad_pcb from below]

Board: 2 copper layers, 68.5 x 53.4 mm, 48 parts (5 on the bottom side), 37 nets.

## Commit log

2018-04-17 Adding Wize Shield, RevPA
    Prototype A version, made by Gaston Schelotto
    [wize-shield-B.Mask.gbs, wize-shield-Back.gbl, wize-shield-Dwgs.User.gbr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]
2018-08-23 Reorganisation
    Reorganisation of the folder to separate between versions PA and PB
    [Arduino UNO R3 shield - full.dxf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]
2019-08-26 Adding K1-RevA
    [Arduino UNO R3 shield - full.dxf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]
2019-08-26 Adding the laser-cutting enclosure files
